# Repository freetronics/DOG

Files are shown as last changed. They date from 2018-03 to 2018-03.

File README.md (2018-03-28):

DOG
===
http://www.freetronics.com/products/watchdog-timer-module

Design files for Freetronics watchdog timer module.

Connects to your Arduino or other microcontroller project and makes sure it keeps running by watching for a “heartbeat” signal. If the signal stops, the watchdog uses the microcontroller reset line to kick it back into life.

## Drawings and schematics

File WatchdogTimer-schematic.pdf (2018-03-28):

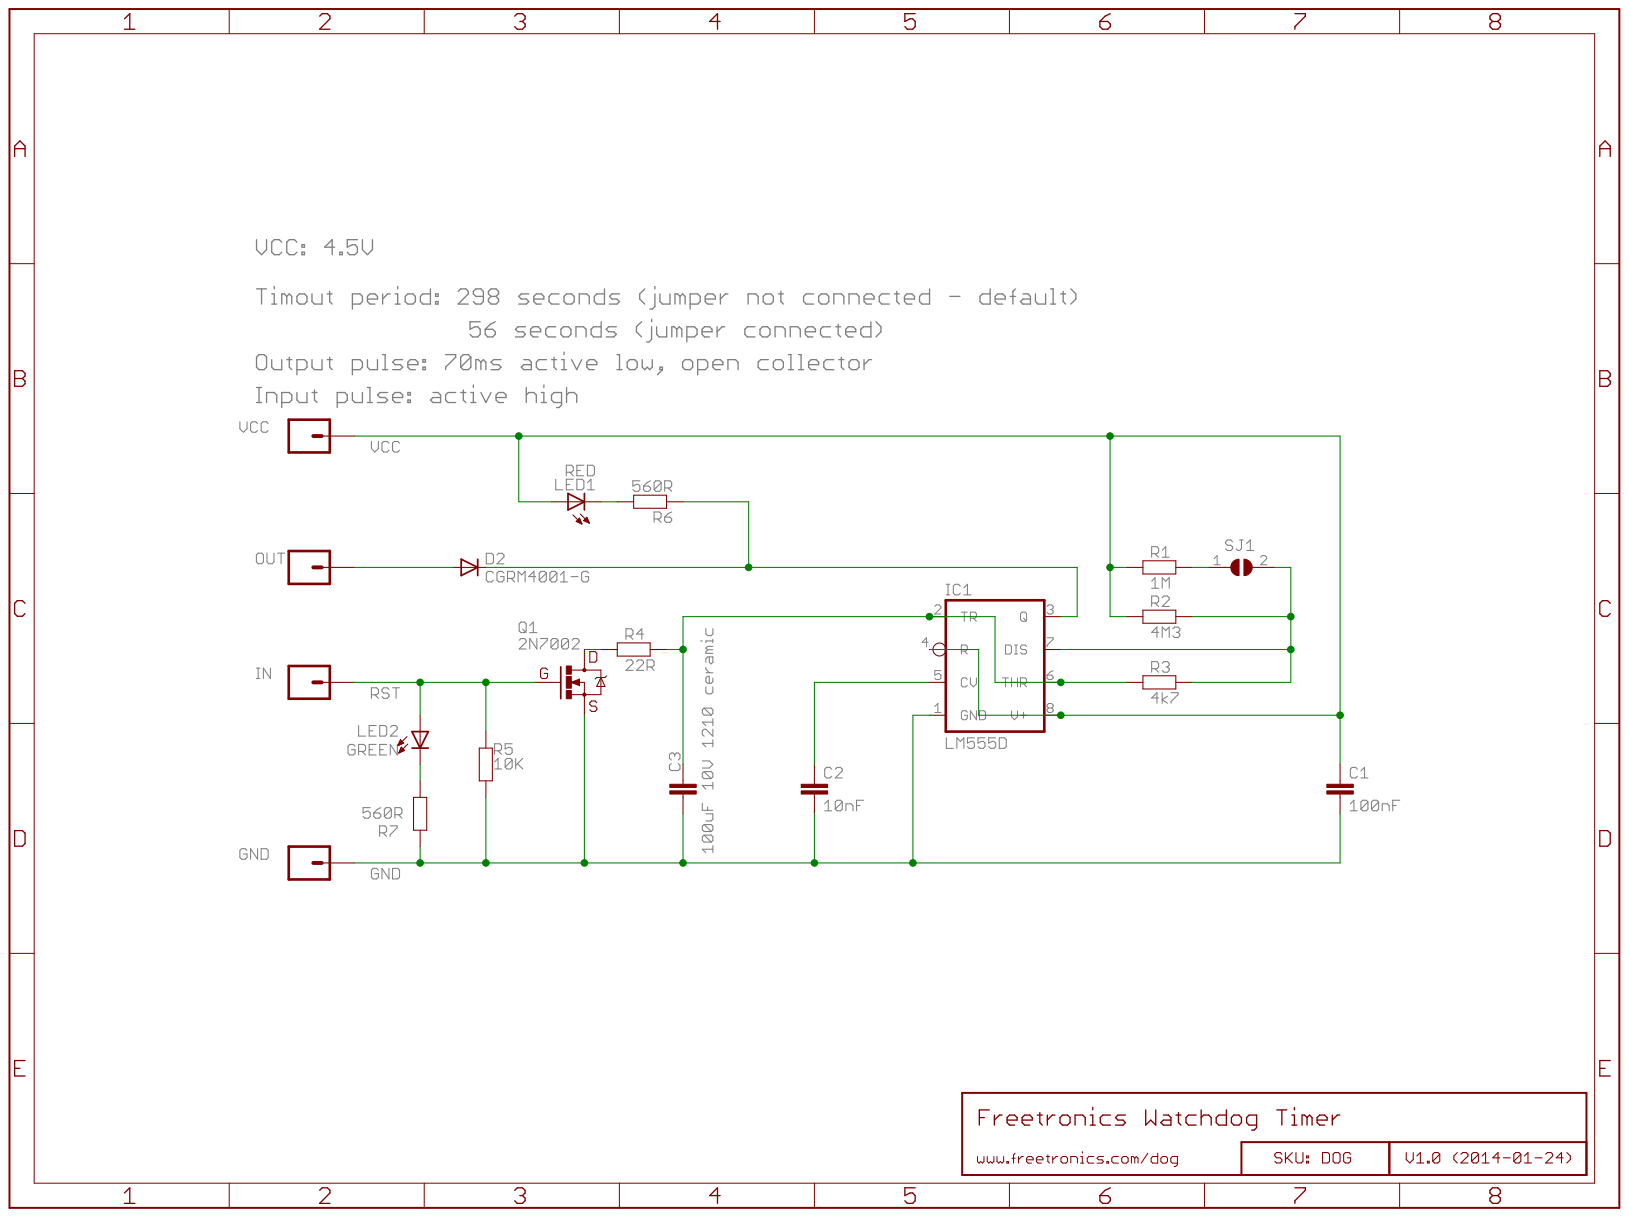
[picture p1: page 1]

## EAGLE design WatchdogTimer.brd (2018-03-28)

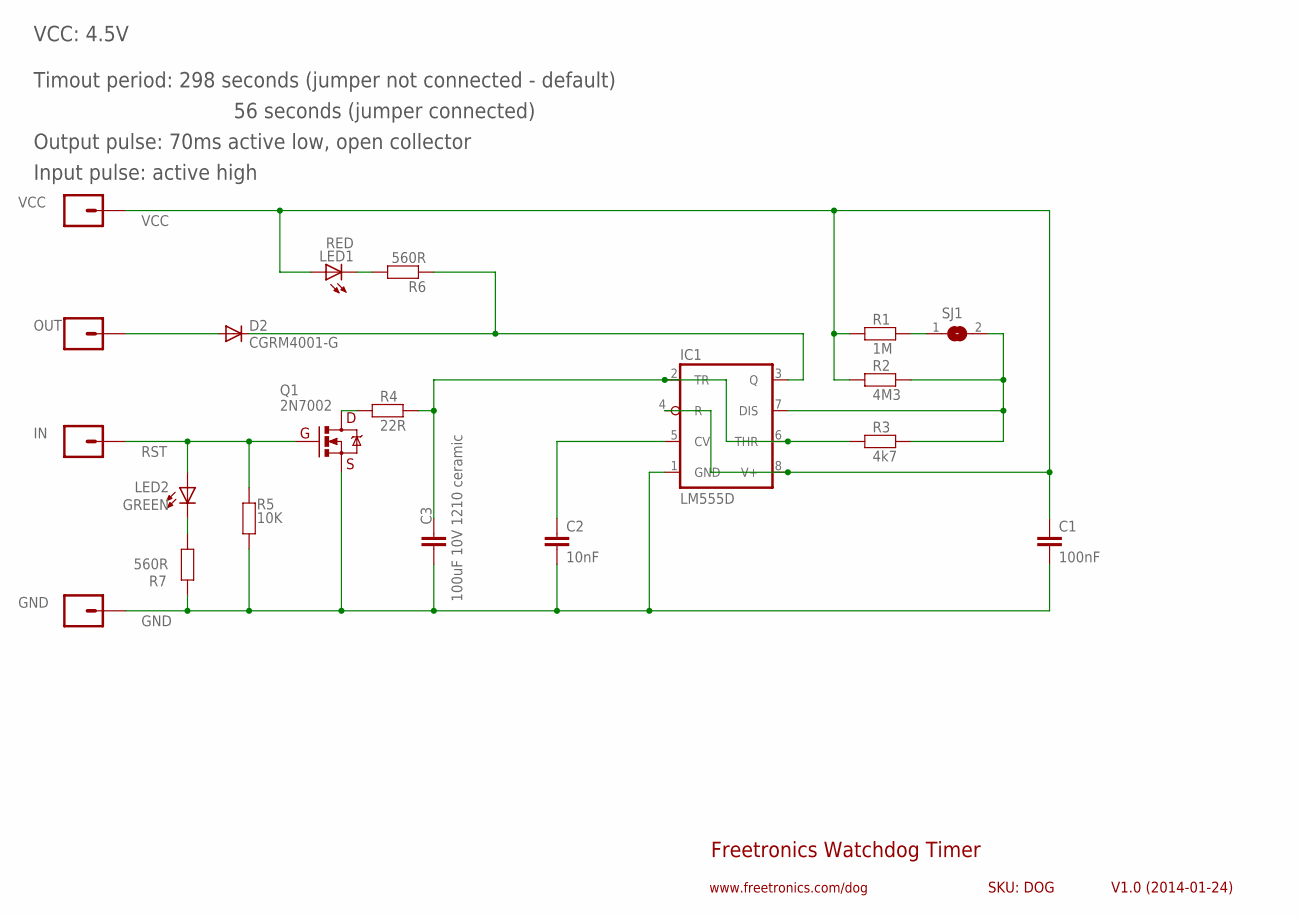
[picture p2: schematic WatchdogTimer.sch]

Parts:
C1: 100nF; 0603
C2: 10nF; 0603
C3: 100uF 10V 1210 ceramic; C1210
D2: CGRM4001-G; SOD-123_MINI-SMA
GND: M01PTH; 1X01
IC1: LM555D; SO08
IN: M01PTH; 1X01
LED1: RED; LED-0603
LED2: GREEN; LED-0603
OUT: M01PTH; 1X01
Q1: 2N7002; SOT23-3
R1: 1M; 0603
R2: 4M3; 0603
R3: 4k7; 0603
R4: 22R; 0603
R5: 10K; 0603
R6, R7: 560R; 0603
SJ1: SJ
VCC: M01PTH; 1X01

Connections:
C4: C3.1, IC1.2 (TR), IC1.6 (THR), R3.1, R4.2
GND: C1.2, C2.2, C3.2, GND.1, IC1.1 (GND), Q1.2 (S), R5.1, R7.2
unnamed: Q1.3 (D), R4.1
unnamed: LED2.C, R7.1
unnamed: R1.2, SJ1.1
unnamed: IC1.7 (DIS), R2.2, R3.2, SJ1.2
unnamed: LED1.C, R6.2
unnamed: C2.1, IC1.5 (CV)
unnamed: D2.A, OUT.1
RST: IN.1, LED2.A, Q1.1 (G), R5.2
TO: D2.C, IC1.3 (Q), R6.1
VCC: C1.1, IC1.4 (R), IC1.8 (V+), LED1.A, R1.1, R2.1, VCC.1

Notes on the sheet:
Freetronics Watchdog Timer
V1.0 (2014-01-24)
www.freetronics.com/dog
SKU: DOG
VCC: 4.5V
Timout period: 298 seconds (jumper not connected - default)
56 seconds (jumper connected)
Output pulse: 70ms active low, open collector
Input pulse: active high

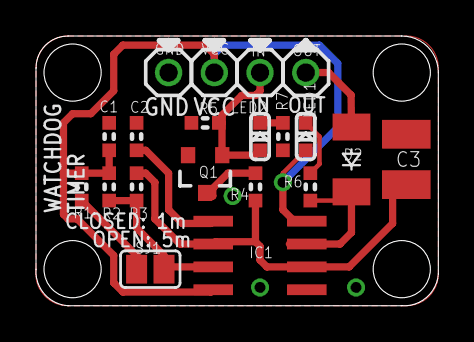
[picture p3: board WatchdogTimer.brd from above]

Board: 2 copper layers, 22.4 x 15.0 mm, 20 parts (0 on the bottom side), 12 nets.

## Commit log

2013-12-15 Initial project
    [WatchdogTimer.brd, WatchdogTimer.sch]
2014-01-24 Replaced main timing cap with 1206 tantalum for size reasons Updates to routing and labels
    [WatchdogTimer.brd, WatchdogTimer.sch]
2014-10-07 Add schematic PDF
2018-03-28 Improved parts designators
    [WatchdogTimer.brd]

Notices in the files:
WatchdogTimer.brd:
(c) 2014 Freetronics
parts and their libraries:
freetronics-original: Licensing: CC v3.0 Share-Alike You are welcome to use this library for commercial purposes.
